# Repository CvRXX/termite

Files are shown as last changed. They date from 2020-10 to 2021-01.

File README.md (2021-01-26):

# Termite Devboard

Termite is an open source hardware devboard aimed at embedded library developers.

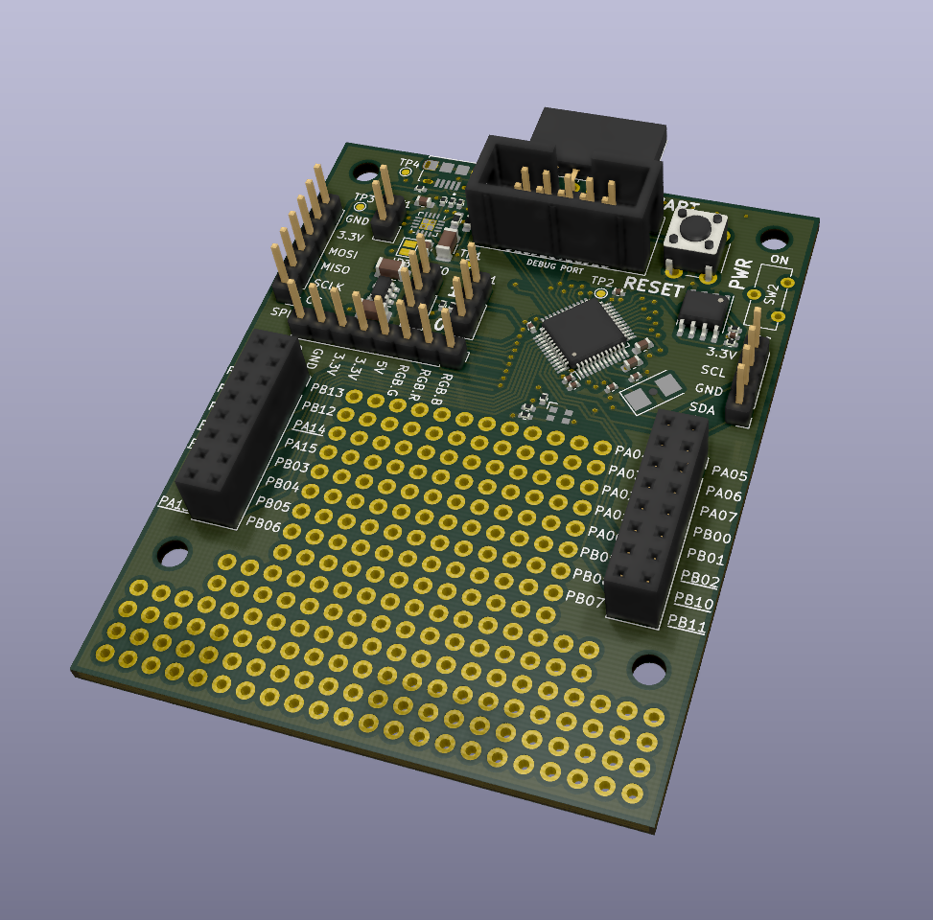
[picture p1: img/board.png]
The devboard

## Features
  * An stm32f103 cortex m3 microcontroller.
  * A protoboard space to mount components on.
  * An RGB led.
  * Support for lithium ion batteries as power source.
  * Charging of lithium ion batteries.
  * 128Kb of external onboard flash memory

## The idea
The idea came from my teacher who is developing multiple embedded libraries.
These libraries have support for many different types of displays, sensors, etc.
Everytime a change is made to the library my teacher had to hookup the sensors to an devboard. 
His wish was to have a devboard cheap enough he could solder the components on and leave them on.
This is what termite was designed for.

## Power
The board can be powered by 5v or 3.3 volt. 
There is a usb connector which can be used for power as well. 
Another option is to connect a lithium ion battery. 
If there is a voltage on the 5v rail a connected battery will be charged.

### WARNINGS about battery usage: 
  1. Only connect lithium ion batteries with a voltage of 3.7V marked on them.
  2. Don't connect batteries with a capacity less than 250mAh.
  3. Only connect batteries with an integrated protection circuit.
  4. Don't charge your board unattended. 

### Status leds:

| Green led  | Red led | Meaning |
| --- | --- | --- |
| Off  | Off  | No external power connected.
| On  | Off  | External power connected, battery full or not connected.
| On  | On  | External power connected, battery charging
| On  | Blinking  | External power connected, issue with battery detected.

## Flashing the microcontroller
The board include an IDC header that matches the pinout of the stlink-v2.
You need an IDC cable to connect between the flash tool and the board. 
After that it flashes just as any other stm microcontroller.

## Opening the files
To open the design files you need kicad. 
It's free software so you can just download it.

## Producing a board
If you want to produce a board you can export all the needed files from kicad.
It is hard (read impossible) to solder the battery charging chip with a normal soldering iron.
So if you want the battery charging you need to arrange for better equipment or arrange for pick and placing the board.

The board is 4 layer and can be produced by almost every common pcb factory.

If there are any problems I'm happy to help you on your way.
Just contact me!

## Testing the board
After production a testing script is available to check if the board is functioning oke. 
You can find the script and it's docs [here](https://github.com/CvRXX/termite-test-firmware).

## Examples with the termite board.
  * [A temperature sensor for painting scouting boats.](https://github.com/CvRXX/termite-demo)

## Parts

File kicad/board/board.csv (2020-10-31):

Comment | Designator | Footprint | LCSC
103565 3.7v lipo battery | BT1 | Connector_PinHeader_2.54mm:PinHeader_1x02_P2.54mm_Vertical | C152154
8pF | C1,C2 | Capacitor_SMD:C_0402_1005Metric | C26408
10nf | C11 | Capacitor_SMD:C_0603_1608Metric | C57112
1uF | C4,C12,C13 | Capacitor_SMD:C_1206_3216Metric | C1848
100nF | C5,C6,C7,C9,C14 | Capacitor_SMD:C_0402_1005Metric | C1525
4.7uF | C3,C8,C10 | Capacitor_SMD:C_0603_1608Metric | C19666
FM-B2020RGBA-HG | D1 | components:FM-B2020RGBA-HG | C108793
i2c_connector | J1 | Connector_PinHeader_2.54mm:PinHeader_1x04_P2.54mm_Vertical | C124378
uart_connector | J2 | Connector_PinSocket_2.54mm:PinSocket_1x06_P2.54mm_Horizontal | C492414
spi_connector | J3 | Connector_PinHeader_2.54mm:PinHeader_1x06_P2.54mm_Vertical | C492405
debug header | J4 | Connector_IDC:IDC-Header_2x05_P2.54mm_Vertical | C5665
powerheader | J5 | Connector_PinHeader_2.54mm:PinHeader_1x08_P2.54mm_Vertical | C124381
USB_B_Micro | J6 | components:AMPHENOL_10118194-0001LF | C132563
gpioheader A | J7 | Connector_PinSocket_2.54mm:PinSocket_2x08_P2.54mm_Vertical
gpioheader B | J8 | Connector_PinSocket_2.54mm:PinSocket_2x08_P2.54mm_Vertical
boot0_jumper | JP1 | Connector_PinHeader_2.54mm:PinHeader_1x03_P2.54mm_Vertical | C49257
boot1_jumper | JP2 | Connector_PinHeader_2.54mm:PinHeader_1x03_P2.54mm_Vertical | C49257
chargerOverride | JP3 | Jumper:SolderJumper-2_P1.3mm_Open_Pad1.0x1.5mm
1.13kΩ | R1 | Resistor_SMD:R_0402_1005Metric | C67014
10kΩ | R2 | Resistor_SMD:R_0402_1005Metric | C25744
68Ω | R3 | Resistor_SMD:R_0402_1005Metric | C25131
15Ω | R4,R5 | Resistor_SMD:R_0402_1005Metric | C25083
1.5kΩ ± 1% | R6 | Resistor_SMD:R_0402_1005Metric | C98835
4.7kΩ | R7,R8,R9,R10 | Resistor_SMD:R_0402_1005Metric | C25900
reset button | SW1 | components:K2-6639DP-E4SW-04 | C223748
chargerOutput | TP1 | TestPoint:TestPoint_Pad_D2.0mm
clockTestingPoint | TP2 | TestPoint:TestPoint_Pad_D2.0mm
BQ24075 | U1 | Package_DFN_QFN:QFN-16-1EP_3x3mm_P0.5mm_EP1.7x1.7mm | C15464
STM32F103C8Tx | U2 | Package_QFP:LQFP-48_7x7mm_P0.5mm | C8304
LP5907MFX-3.3 | U3 | Package_TO_SOT_SMD:SOT-23-5 | C80670
CAT24C128 | U4 | Package_SO:SOIC-8_3.9x4.9mm_P1.27mm | C81195
X322516MLB4SI | Y1 | components:YSX321SL | C13738

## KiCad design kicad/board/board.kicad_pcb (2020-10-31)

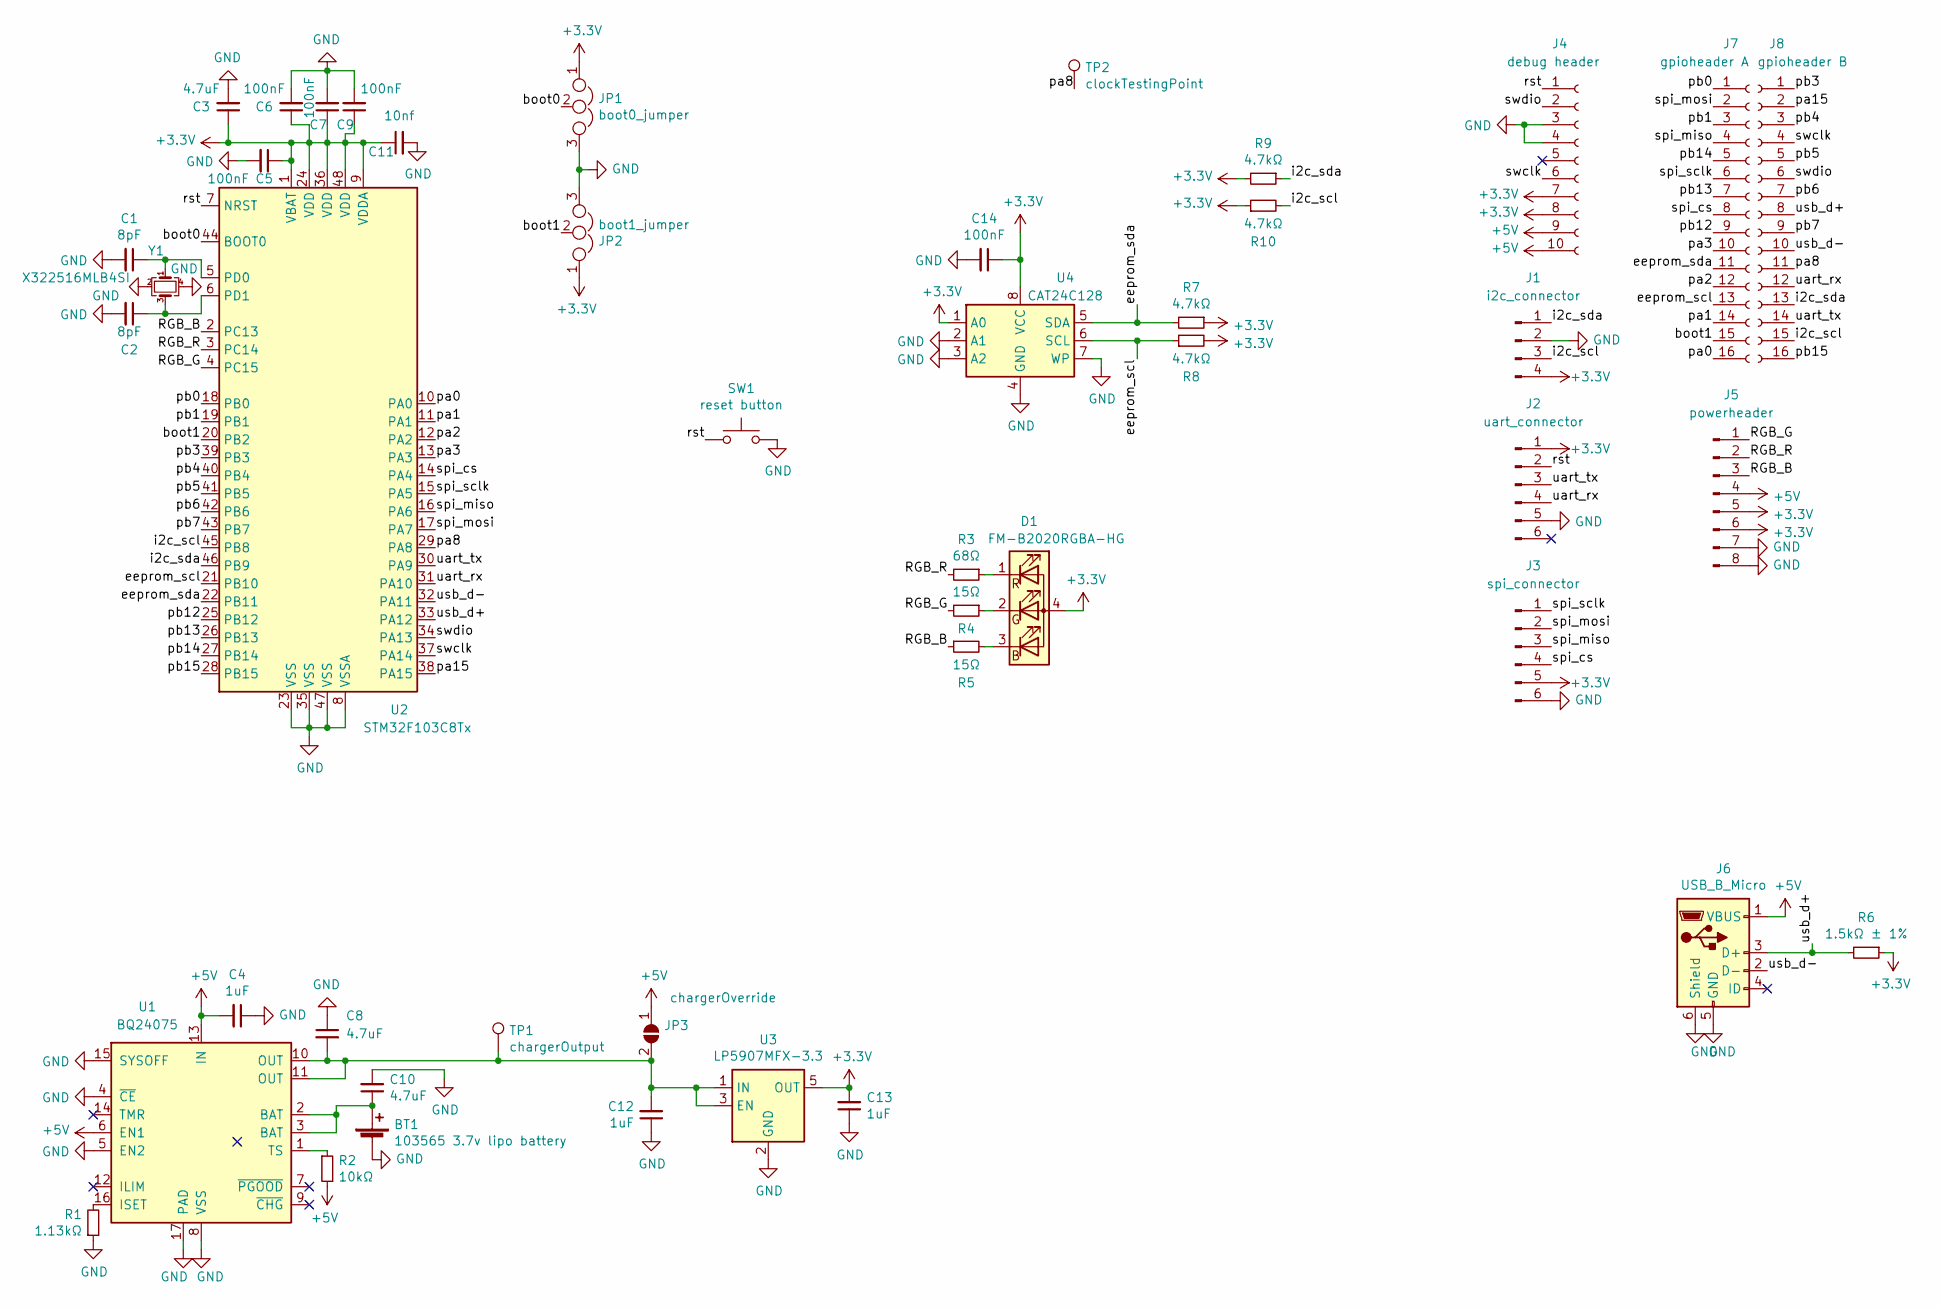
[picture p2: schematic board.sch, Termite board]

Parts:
BT1: 103565 3.7v lipo battery; PinHeader_1x02_P2.54mm_Vertical; lcsc C152154
C1, C2: 8pF; C_0402_1005Metric; lcsc C26408
C3, C8, C10: 4.7uF; C_0603_1608Metric; lcsc C19666
C4, C12, C13: 1uF; C_1206_3216Metric; lcsc C1848
C5, C6, C7, C9, C14: 100nF; C_0402_1005Metric; lcsc C1525
C11: 10nf; C_0603_1608Metric; lcsc C57112
D1: FM-B2020RGBA-HG; lcsc C108793
J1: i2c_connector; PinHeader_1x04_P2.54mm_Vertical; lcsc C124378
J2: uart_connector; PinSocket_1x06_P2.54mm_Horizontal; lcsc C492414
J3: spi_connector; PinHeader_1x06_P2.54mm_Vertical; lcsc C492405
J4: debug header; IDC-Header_2x05_P2.54mm_Vertical; lcsc C5665
J5: powerheader; PinHeader_1x08_P2.54mm_Vertical; lcsc C124381
J6: USB_B_Micro; AMPHENOL_10118194-0001LF; lcsc C132563
J7: gpioheader A; PinSocket_2x08_P2.54mm_Vertical
J8: gpioheader B; PinSocket_2x08_P2.54mm_Vertical
JP1: boot0_jumper; PinHeader_1x03_P2.54mm_Vertical; lcsc C49257
JP2: boot1_jumper; PinHeader_1x03_P2.54mm_Vertical; lcsc C49257
JP3: chargerOverride; SolderJumper-2_P1.3mm_Open_Pad1.0x1.5mm
R1: 1.13kΩ; R_0402_1005Metric; lcsc C67014
R2: 10kΩ; R_0402_1005Metric; lcsc C25744
R3: 68Ω; R_0402_1005Metric; lcsc C25131
R4, R5: 15Ω; R_0402_1005Metric; lcsc C25083
R6: 1.5kΩ ± 1%; R_0402_1005Metric; LCSC C98835
R7, R8, R9, R10: 4.7kΩ; R_0402_1005Metric; LCSC C25900
SW1: reset button; K2-6639DP-E4SW-04; lcsc C223748
TP1: chargerOutput; TestPoint_Pad_D2.0mm
TP2: clockTestingPoint; TestPoint_Pad_D2.0mm
U1: BQ24075; QFN-16-1EP_3x3mm_P0.5mm_EP1.7x1.7mm; lcsc C15464
U2: STM32F103C8Tx; LQFP-48_7x7mm_P0.5mm; lcsc C8304
U3: LP5907MFX-3.3; SOT-23-5; lcsc C80670
U4: CAT24C128; SOIC-8_3.9x4.9mm_P1.27mm; lcsc C81195
Y1: X322516MLB4SI; YSX321SL; lcsc C13738

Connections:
+3V3: C3.1, C5.1, C6.1, C7.1, C9.1, C11.1, C13.2, C14.1, D1.4 (A), J1.4, J2.1, J3.5, J4.7, J4.8, J5.5, J5.6, JP1.1, JP2.1, R6.1, R7.1, R8.2, R9.2, R10.1, U2.1 (VBAT), U2.9 (VDDA), U2.24 (VDD), U2.36 (VDD), U2.48 (VDD), U3.5 (OUT), U4.1 (A0), U4.8 (VCC)
+5V: C4.2, J4.9, J4.10, J5.4, J6.1 (VBUS), JP3.1 (A), R2.2, U1.6 (EN1), U1.13 (IN)
/RGB_B: J5.3, R5.1, U2.2 (PC13)
/RGB_G: J5.1, R4.2, U2.4 (PC15)
/RGB_R: J5.2, R3.2, U2.3 (PC14)
/boot0: JP1.2, U2.44 (BOOT0)
/boot1: J7.15, JP2.2, U2.20 (PB2)
/eeprom_scl: J7.13, R8.1, U2.21 (PB10), U4.6 (SCL)
/eeprom_sda: J7.11, R7.2, U2.22 (PB11), U4.5 (SDA)
/i2c_scl: J1.3, J8.15, R10.2, U2.45 (PB8)
/i2c_sda: J1.1, J8.13, R9.1, U2.46 (PB9)
/pa0: J7.16, U2.10 (PA0)
/pa1: J7.14, U2.11 (PA1)
/pa2: J7.12, U2.12 (PA2)
/pa3: J7.10, U2.13 (PA3)
/pa8: J8.11, TP2.1, U2.29 (PA8)
/pa15: J8.2, U2.38 (PA15)
/pb0: J7.1, U2.18 (PB0)
/pb1: J7.3, U2.19 (PB1)
/pb3: J8.1, U2.39 (PB3)
/pb4: J8.3, U2.40 (PB4)
/pb5: J8.5, U2.41 (PB5)
/pb6: J8.7, U2.42 (PB6)
/pb7: J8.9, U2.43 (PB7)
/pb12: J7.9, U2.25 (PB12)
/pb13: J7.7, U2.26 (PB13)
/pb14: J7.5, U2.27 (PB14)
/pb15: J8.16, U2.28 (PB15)
/rst: J2.2, J4.1, SW1.1, U2.7 (NRST)
/spi_cs: J3.4, J7.8, U2.14 (PA4)
/spi_miso: J3.3, J7.4, U2.16 (PA6)
/spi_mosi: J3.2, J7.2, U2.17 (PA7)
/spi_sclk: J3.1, J7.6, U2.15 (PA5)
/swclk: J4.6, J8.4, U2.37 (PA14)
/swdio: J4.2, J8.6, U2.34 (PA13)
/uart_rx: J2.4, J8.12, U2.31 (PA10)
/uart_tx: J2.3, J8.14, U2.30 (PA9)
/usb_d+: J6.3 (D+), J8.8, R6.2, U2.33 (PA12)
/usb_d-: J6.2 (D-), J8.10, U2.32 (PA11)
GND: BT1.2 (-), C1.2, C2.2, C3.2, C4.1, C5.2, C6.2, C7.2, C8.1, C9.2, C10.2, C11.2, C12.1, C13.1, C14.2, J1.2, J2.5, J3.6, J4.3, J4.4, J5.7, J5.8, J6.5 (GND), J6.6 (Shield), JP1.3, JP2.3, R1.1, SW1.2, U1.4 (~CE), U1.5 (EN2), U1.8 (VSS), U1.15 (SYSOFF), U1.17 (PAD), U2.8 (VSSA), U2.23 (VSS), U2.35 (VSS), U2.47 (VSS), U3.2 (GND), U4.2 (A1), U4.3 (A2), U4.4 (GND), U4.7 (WP), Y1.2, Y1.4
unnamed: BT1.1 (+), C10.1, U1.2 (BAT), U1.3 (BAT)
unnamed: C1.1, U2.5 (PD0), Y1.1
unnamed: C2.1, U2.6 (PD1), Y1.3
unnamed: C8.2, C12.2, JP3.2 (B), TP1.1, U1.10 (OUT), U1.11 (OUT), U3.1 (IN), U3.3 (EN)
unnamed: D1.1 (RK), R3.1
unnamed: D1.2 (GK), R4.1
unnamed: D1.3 (BK), R5.2
unnamed: R1.2, U1.16 (ISET)
unnamed: R2.1, U1.1 (TS)

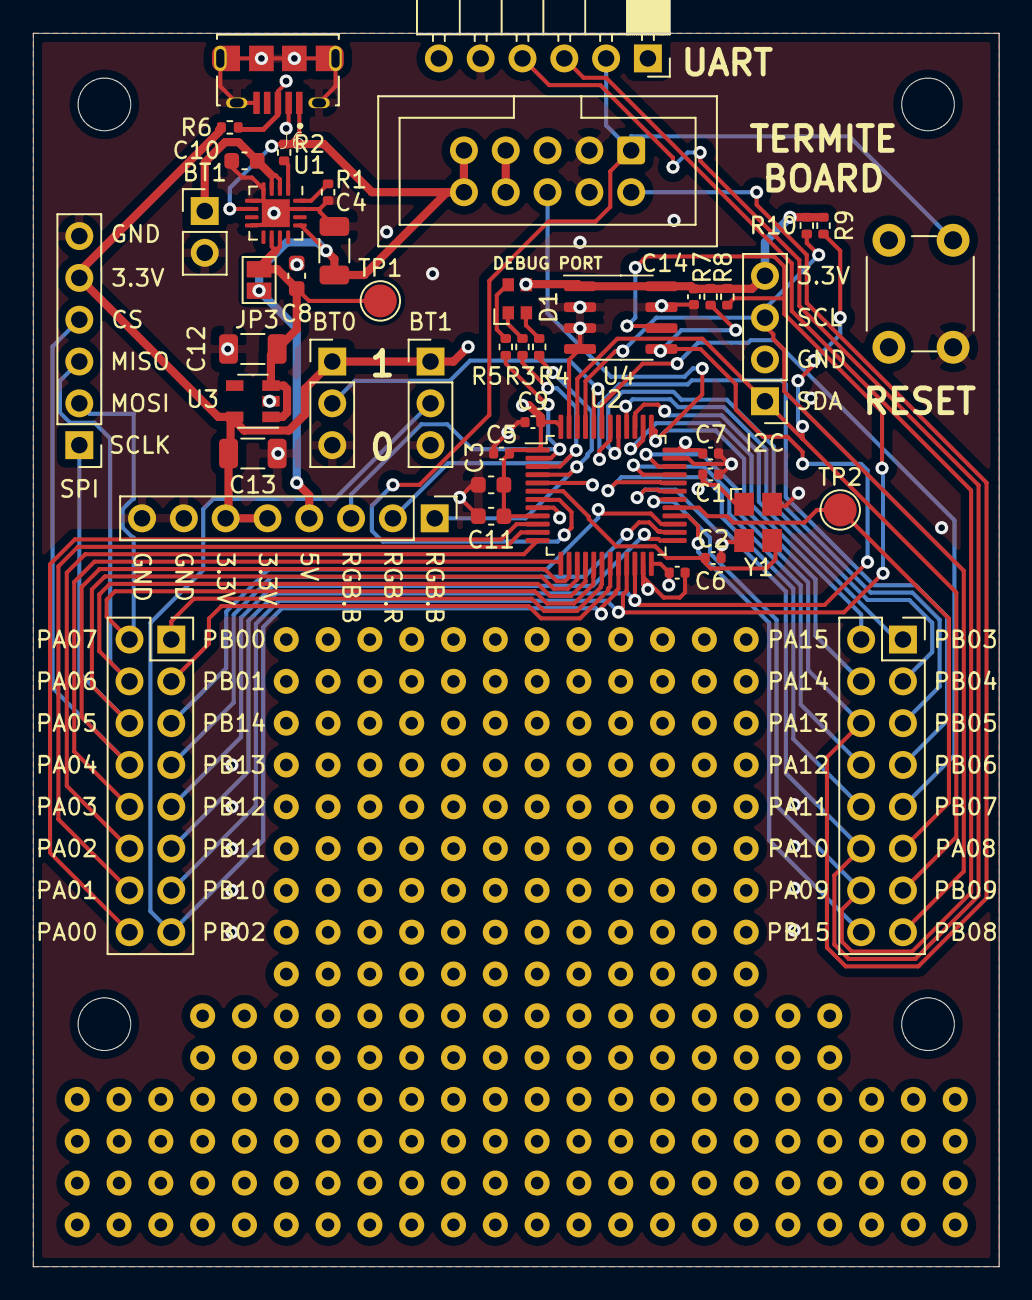
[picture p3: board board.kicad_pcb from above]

Board: 4 copper layers, 58.7 x 74.9 mm, 45 parts (0 on the bottom side), 49 nets.

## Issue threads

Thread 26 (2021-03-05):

Might have broken a board by connecting a battery with reverse polarity.

CvRXX, 2021-03-05:
Will have to see if that is protected.
